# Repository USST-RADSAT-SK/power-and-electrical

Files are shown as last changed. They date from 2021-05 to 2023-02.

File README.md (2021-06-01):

# power-and-electrical

## How to Download GitBash
  
  Gitbash is a terminal that you use to execute "git" commands and its highly recommended that you download it 
  
  Use the following link
  https://git-scm.com/downloads
  
## How to Copy a Repo

  Make a folder on your local drive (I make a folder on my desktop)
  
  go into that folder and right click and open gitbash at that location
  
  find the green button in the github that says "Code"
  
  click and copy the URL
  
  go back into the gitbash enter
  
  "git clone [URL]" 

  Now if you want to make changes to a file please make a branch 
  
## How To View a Branch

  Say you want to do a quick check on the progress for the PCB board
  
  use the following commands in git bash
  
  "git checkout [name of branch]"
  
  In the case that KiCad is not updating automatically use the following procedure:
  
  - open project file with "open with..." in file directory 

  If you quickly want to check when the last changes were done to a branch use
  
  "git log"
  
  scroll up & you will see the most recent commit and who did it
  
## How To Make a Branch
  
  a branch is like a copy of files that you can edit on your local drive where you dont have to worry about messing up the main code
  
  make sure you are in the right directory
  
  "git branch [name of the branch]"

  keep the name of the branch short and sweet no need to make it complitcated

## How to Commit a Change

  Once gitbash is opened you want to make sure you are in the right file directory you want to use the command 
  
  "git status"
  
  to check if you saved your files (it will show up as red)
  
  "Git add [filename]"
  
  this will prepare your file to be commited
  
  "git status"
  
  the file name should be green now
  
  "git commit -m "[changes you made as a comment]" "
  
  this will commit your changes 
  
  "git push"
  
  this will save your changes into the branch

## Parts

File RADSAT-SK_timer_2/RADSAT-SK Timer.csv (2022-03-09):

Source: | C:\Users\gundo\Desktop\P&E\power-and-electrical\RADSAT-SK Timer\RADSAT-SK Timer.sch
Date: | 2022-03-02 14:46
Tool: | Eeschema (5.1.12)-1
Generator: | C:\Program Files\KiCad\bin\scripting\plugins/bom_csv_grouped_by_value_with_fp.py
Component Count: | 124
Ref | Qnty | Value | Cmp name | Footprint | Description | Vendor
BT201, BT202, | 2 | Battery_Cell | Battery_Cell | Battery:BatteryHolder_Keystone_1060_1x2032 | Single-cell battery
C101, C102, C105, C106, C107, C108, | 6 | 330u | CP | Capacitor_Tantalum_SMD:CP_EIA-7343-30_AVX-N_Pad2.25x2.55mm_HandSolder | Polarized capacitor
C103, C104, C109, C110, C111, C112, C113, C114, | 8 | 100n | C | Capacitor_SMD:C_0805_2012Metric | Unpolarized capacitor
C204, | 1 | 10uF | C | Capacitor_SMD:C_0805_2012Metric | Unpolarized capacitor
C205, | 1 | 0.1uF | C | Capacitor_SMD:C_0805_2012Metric | Unpolarized capacitor
C207, | 1 | 1.5nF | C | Capacitor_SMD:C_0805_2012Metric | Unpolarized capacitor
C208, | 1 | 22uF | C | Capacitor_SMD:C_1210_3225Metric_Pad1.33x2.70mm_HandSolder | Unpolarized capacitor
D201, | 1 | 5.0SMDJ5.0A | SM6T6V8A | Diode_SMD:D_SMC_Handsoldering | 600W unidirectional Transil Transient Voltage Suppressor, 6.8Vrwm, DO-214AA
D203, | 1 | MBRM120LT3G | D_Schottky | Diode_SMD:D_Powermite_AK | Schottky diode
D204, | 1 | BAT54CDW | BAT54CDW | Package_TO_SOT_SMD:SOT-363_SC-70-6_Handsoldering | Schottky diode array 2 pair Com K
D205, D206, | 2 | LED | LED | LED_SMD:LED_0603_1608Metric_Pad1.05x0.95mm_HandSolder | Light emitting diode
H101, H102, H103, H104, | 4 | MountingHole | MountingHole | MountingHole:MountingHole_3.2mm_M3_ISO7380_Pad_TopBottom | Mounting Hole without connection
J101, J103, | 2 | Conn_02x26_Odd_Even | Conn_02x26_Odd_Even | Connector_PinSocket_2.54mm:PinSocket_2x26_P2.54mm_Vertical | Generic connector, double row, 02x26, odd/even pin numbering scheme (row 1 odd numbers, row 2 even numbers), script generated (kicad-library-utils/schlib/autogen/connector/)
J201, | 1 | Conn_01x07 | Conn_01x07 | Connector_Molex:Molex_PicoBlade_53047-0710_1x07_P1.25mm_Vertical | Generic connector, single row, 01x07, script generated (kicad-library-utils/schlib/autogen/connector/)
J202, | 1 | Conn_01x05 | Conn_01x05 | Connector_Hirose:Hirose_DF13-05P-1.25DSA_1x05_P1.25mm_Vertical | Generic connector, single row, 01x05, script generated (kicad-library-utils/schlib/autogen/connector/)
J203, | 1 | Conn_01x03 | Conn_01x03 | Connector_Hirose:Hirose_DF13C_CL535-0403-5-51_1x03-1MP_P1.25mm_Vertical | Generic connector, single row, 01x03, script generated (kicad-library-utils/schlib/autogen/connector/)
J204, J205, J206, | 3 | Conn_01x02 | Conn_01x02 | Connector_Hirose:Hirose_DF13-02P-1.25DSA_1x02_P1.25mm_Vertical | Generic connector, single row, 01x02, script generated (kicad-library-utils/schlib/autogen/connector/)
L201, | 1 | 10uH | L | Sumida_inductor:Sumida_inductor | Inductor
Q101, Q102, Q103, Q104, Q105, Q106, Q107, Q108, Q109, Q201, Q202, Q204, Q205, Q206, Q207, | 15 | IRLML2060 | IRLML2060 | Package_TO_SOT_SMD:SOT-23_Handsoldering | 1.2A Id, 60V Vds, 480mOhm Rds, N-Channel HEXFET Power MOSFET, SOT-23
R101, R103, R107, R113, R114, R117, R118, R124, R126, R203, R221, | 11 | 1M | R | Resistor_SMD:R_0805_2012Metric | Resistor
R102, R111, R115, R116, R133, R134, R202, R204, R211, R213, R215, R220, | 12 | 100 | R | Resistor_SMD:R_0805_2012Metric | Resistor
R104, R119, R120, | 3 | 1K | R | Resistor_SMD:R_0805_2012Metric | Resistor
R105, R121, R122, | 3 | 3.48M | R | Resistor_SMD:R_0805_2012Metric | Resistor
R106, R123, R125, | 3 | 442K | R | Resistor_SMD:R_0805_2012Metric | Resistor
R108, R109, R110, R112, R127, R128, R129, R130, R131, R132, R135, R136, R209, R210, R212, R214, R216, R217, | 18 | 1k | R | Resistor_SMD:R_0805_2012Metric | Resistor
R137, | 1 | 5.1M | R | Resistor_SMD:R_0805_2012Metric | Resistor
R201, | 1 | 3M | R | Resistor_SMD:R_0805_2012Metric | Resistor
R205, | 1 | 60.4K | R | Resistor_SMD:R_0805_2012Metric | Resistor
R206, | 1 | 15k | R | Resistor_SMD:R_0805_2012Metric | Resistor
R207, | 1 | 619k | R | Resistor_SMD:R_0805_2012Metric | Resistor
R208, | 1 | 200k | R | Resistor_SMD:R_0805_2012Metric | Resistor
SW201, SW202, SW203, SW204, SW205, SW206, | 6 | SW_Push | SW_Push | Connector_Hirose:Hirose_DF13-02P-1.25DSA_1x02_P1.25mm_Vertical | Push button switch, generic, two pins
U101, U102, U103, | 3 | LM397MF | LM397MF | Package_TO_SOT_SMD:TSOT-23-5_HandSoldering
U104, | 1 | CD4052B | CD4052B | Package_SO:TSSOP-16_4.4x5mm_P0.65mm | CMOS double 4-channel analog multiplexer/demultiplexer, TSSOP-16/DIP-16/SOIC-16
U202, | 1 | LTC3440EMSPBF | LTC3440EMSPBF | Package_SO:MSOP-10_3x3mm_P0.5mm
U230, U240, U250, U260, | 4 | CPC1117N | CPC1117N | Package_SO:SOP-4_3.8x4.1mm_P2.54mm | Form B, Solid State Relay (Photo MOSFET) 60V, 0.15A, 16Ohm, SO-4

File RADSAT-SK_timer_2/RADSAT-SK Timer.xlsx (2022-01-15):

Source: | C:\Users\riley\USST\RADSAT-SK\power-and-electrical\RADSAT-SK Timer\RADSAT-SK Timer.sch
Date: | 10/20/2021 6:26PM
Tool: | Eeschema (5.1.10)-1
Generator: | C:\Program Files\KiCad\bin\scripting\plugins/bom_csv_grouped_by_value_with_fp.py
Component Count: | 116
Total Component Cost: | $80.62
Ref | Qnty | Value | Cmp name | Footprint | Description/Notes | Datasheet | Product URL | Price | Related Components | Price2 | Price total | Column1
BT201, BT202, | 2 | Battery_Cell | Battery_Cell | Battery:BatteryHolder_Keystone_1060_1x2032 | BATT HLDR COIN 20MM 1/2 CEL SMD | https://www.keyelco.com/userAssets/file/M65p3.pdf | https://www.digikey.ca/en/products/detail/keystone-electronics/1060TR/303557 | $2.12 | https://www.mouser.ca/ProductDetail/Panasonic-Industrial-Devices/CR-2025-F2N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 | $1.61 | $7.46
C101, C102, C105, C106, C107, C108, | 6 | 330u | CP | Capacitor_Tantalum_SMD:CP_EIA-7343-30_AVX-N_Pad2.25x2.55mm_HandSolder | 330 µF Molded Tantalum Capacitors 10 V 2917 (7343 Metric) 500mOhm @ 100kHz |  | https://www.digikey.ca/en/products/detail/kyocera-avx/F931A337KNC/4005190 | $3.36 |  |  | $20.16
C103, C104, C109, C110, C111, C112, C113, C114, C204 | 9 | 100n | C | Capacitor_SMD:C_0805_2012Metric | Unpolarized capacitor |  | https://www.digikey.ca/en/products/detail/tdk-corporation/C2012X7R1H104K085AA/2732969 | $0.15 |  |  | $1.35
C204, | 1 | 10uF | C | Capacitor_SMD:C_0805_2012Metric | 10 µF ±20% 6.3V Ceramic Capacitor X5R 0805 (2012 Metric) | https://www.yuden.co.jp/productdata/catalog/mlcc06_e.pdf | https://www.digikey.ca/en/products/detail/taiyo-yuden/JMK212BJ106MG-T/1169928 | $0.41 |  |  | $0.41
C207, | 1 | 1.5nF | C | Capacitor_SMD:C_0805_2012Metric | Unpolarized capacitor |  | https://www.digikey.ca/en/products/detail/tdk-corporation/C2012X5R1E155K125AA/2733062 | $0.41 |  |  | $0.41
C208, | 1 | 22uF | C | Capacitor_SMD:C_1210_3225Metric | 22 µF ±20% 6.3V Ceramic Capacitor X5R 1210 (3225 Metric) | https://ds.yuden.co.jp/TYCOMPAS/ut/detail?pn=JMK325BJ226MY-T%20%20&u=M | https://www.digikey.ca/en/products/detail/taiyo-yuden/JMK325BJ226MY-T/930737 | $1.09 |  |  | $1.09
D205 | 1 | LED | LED | LED_SMD:LED_0603_1608Metric_Pad1.05x0.95mm_HandSolder | Green 571nm LED Indication - Discrete 2V 0603 (1608 Metric) | https://optoelectronics.liteon.com/upload/download/DS22-2000-074/LTST-C190KGKT.PDF | https://www.digikey.ca/en/products/detail/lite-on-inc/LTST-C190KGKT/386815 | $0.33 |  |  | $0.33
D206 | 1 | LED | LED | LED_SMD:LED_0603_1608Metric_Pad1.05x0.95mm_HandSolder | Orange 605nm LED Indication - Discrete 2V 0603 (1608 Metric) |  | https://www.digikey.ca/en/products/detail/lite-on-inc/LTST-C191KFKT/386833 | $0.33 |  |  | $0.33
D201, | 1 | 5.0SMDJ5.0A | D_Zener | Diode_SMD:D_SMC_Handsoldering | 9.2V Clamp 543.6A Ipp Tvs Diode Surface Mount DO-214AB (SMC) | https://www.bourns.com/docs/product-datasheets/5-0smdj.pdf | https://www.digikey.ca/en/products/detail/bourns-inc/5-0SMDJ5-0A/9341763 | $2.33 | https://www.digikey.ca/en/products/detail/vishay-general-semiconductor-diodes-division/BZX884B5V6L-G3-08/14312759 |  | $2.33
D203, | 1 | MBRM120LT3G | D_Schottky | Diode_SMD:D_Powermite_AK | DIODE SCHOTTKY 20V 1A POWERMITE | from boost circuit | https://www.onsemi.com/pdf/datasheet/mbrm120l-d.pdf | https://www.digikey.ca/en/products/detail/onsemi/MBRM120LT3G/1748989 | $0.76 |  |  | $0.76
D204 | 1 | BAT54CDW | BAT54CDW | Package_TO_SOT_SMD:SOT-363_SC-70-6_Handsoldering | Diode Array 2 Pair Common Cathode Schottky 30 V 200mA (DC) Surface Mount 6-TSSOP, SC-88, SOT-363 | https://www.panjit.com.tw/upload/datasheet/BAT54TW_SERIES.pdf | https://www.digikey.ca/en/products/detail/panjit-international-inc/BAT54CDW-R1-00001/14660464 | $0.55 |  |  | $0.55
J101, J103, | 2 | Conn_02x26_Odd_Even | Conn_02x26_Odd_Even | Connector_PinSocket_2.54mm:PinSocket_2x26_P2.54mm_Vertical | CSKB |  | https://www.digikey.ca/en/products/detail/samtec-inc/ESQ-126-39-G-D/3601055 |  |  |  | $0.00 |  | crimps?
J201, | 1 | Conn_01x07 | Conn_01x07 | Connector_Molex:Molex_PicoBlade_53047-0710_1x07_P1.25mm_Vertical | Molex Picoblade 53047 Header and accompanying Picoblade 51047 Connector |  | https://www.digikey.ca/en/products/detail/molex/0530470710/242858 | $0.61 | https://www.digikey.ca/en/products/detail/molex/0510470700/4693261 | $0.52 | $1.13 |  | https://www.digikey.ca/en/products/detail/molex/0500588000/634442
J202, | 1 | Conn_01x05 | Conn_01x05 | Connector_Hirose:Hirose_DF13-05P-1.25DSA_1x05_P1.25mm_Vertical | Generic connector, single row, 01x05, | https://www.mouser.ca/datasheet/2/185/DF13_Catalog_D31687_en-2486995.pdf | https://www.mouser.ca/ProductDetail/Hirose-Connector/DF13-5P-125DSA?qs=Ux3WWAnHpjDJWf8XCjmDFw%3D%3D | $0.59 |  |  | $0.59
J203, | 1 | Conn_01x03 | Conn_01x03 | Connector_Hirose:Hirose_DF13-03P-1.25DSA_1x03_P1.25mm_Vertical | Generic connector, single row, 01x03, |  | https://www.digikey.ca/en/products/detail/hirose-electric-co-ltd/DF13-3P-1-25V-75/9170629 | $0.59 |  |  | $0.59 |  | no vertical through hole :(
J210, (REMOVED WITH RBF CHARGING PIN) | 0 | ZX62WRD-B-5PC | ZX62WRD-B-5PC | CONN_ZX62WRD-B-5PC_HIR:CONN_ZX62WRD-B-5PC_HIR | USB Connector |  | https://www.digikey.ca/en/products/detail/hirose-electric-co-ltd/ZX62WRD-B-5PC/3761053 | $1.76 |  |  | $0.00
L201, | 1 | 10uH | L | **NONSTANDARD NEED TO CREATE*** | FIXED IND 10UH 1A 128.3 MOHM SMD | from boost circuit | https://products.sumida.com/products/pdf/CDRH4D28.pdf | https://www.digikey.ca/en/products/detail/sumida-america-components-inc/CDRH4D28NP-100NC/1059478 | $1.48 |  |  | $1.48
Q101, Q102, Q103, Q104, Q105, Q106, Q107, Q108, Q109, Q201, Q202, Q204, Q205, Q206 ,Q207 | 15 | IRLML2060 | IRLML2060 | Package_TO_SOT_SMD:SOT-23_Handsoldering | 1.2A Id, 60V Vds, 480mOhm Rds, N-Channel HEXFET Power MOSFET, SOT-23 | https://www.infineon.com/dgdl/irlml2060pbf.pdf?fileId=5546d462533600a401535664b7fb25ee | https://www.digikey.ca/en/products/detail/infineon-technologies/irlml2060trpbf/2271899 | $0.63 |  |  | $9.45
R101, R103, R107, R113, R114, R117, R118, R124, R126, R203, R221 | 11 | 1M | R | Resistor_SMD:R_0805_2012Metric | Resistor |  | https://www.digikey.ca/en/products/detail/stackpole-electronics-inc/RMCF0805JT1M00/1757878 | $0.03 |  |  | $0.32
R102, R111, R115, R116, R133, R134, R202, R204, R211, R213, R215, R220 | 12 | 100 | R | Resistor_SMD:R_0805_2012Metric | Resistor |  | https://www.digikey.ca/en/products/detail/stackpole-electronics-inc/RNCP0805FTD100R/2240209 | $0.11 |  |  | $1.28
R104, R108, R109, R110, R112, R119, R120, R127, R128, R129, R130, R131, R132, R135, R136, R209, R210, R212, R214, R216, R217 | 21 | 1k | R | Resistor_SMD:R_0805_2012Metric | Resistor |  | https://www.digikey.ca/en/products/detail/stackpole-electronics-inc/RMCF0805JT1K00/1757881 | $0.03 |  |  | $0.61
R105, R121, R122, | 3 | 3.48M | R | Resistor_SMD:R_0805_2012Metric | Resistor |  | https://www.digikey.ca/en/products/detail/vishay-dale/CRCW08053M48FKEA/1176076 | $0.15 |  |  | $0.45
R106, R123, R125, | 3 | 442K | R | Resistor_SMD:R_0805_2012Metric | Resistor |  | https://www.digikey.ca/en/products/detail/stackpole-electronics-inc/RMCF0805FT442K/1713153 | $0.15 |  |  | $0.45
R137, | 1 | 5.1M | R | Resistor_SMD:R_0805_2012Metric | Resistor |  | https://www.digikey.ca/en/products/detail/stackpole-electronics-inc/RMCF0805FT5M10/1713191 | $0.15 |  |  | $0.15
R201, | 1 | 3M | R | Resistor_SMD:R_0805_2012Metric | Resistor |  | https://www.digikey.ca/en/products/detail/stackpole-electronics-inc/RMCF0402JT3M00/1712450 |  |  |  | $0.00
R205, | 1 | 60.4K | R | Resistor_SMD:R_0805_2012Metric | Resistor |  | https://www.digikey.ca/en/products/detail/stackpole-electronics-inc/RMCF0805FT60K4/1760362 | $0.15 |  |  | $0.15
R206, | 1 | 15k | R | Resistor_SMD:R_0805_2012Metric | Resistor |  | https://www.digikey.ca/en/products/detail/stackpole-electronics-inc/RMCF0805FT15K0/1760487 | $0.15 |  |  | $0.15
R207, | 1 | 619k | R | Resistor_SMD:R_0805_2012Metric | Resistor |  | https://www.digikey.ca/en/products/detail/stackpole-electronics-inc/RMCF0805FT619K/1713291 | $0.15 |  |  | $0.15
R208, | 1 | 200k | R | Resistor_SMD:R_0805_2012Metric | Resistor |  | https://www.digikey.ca/en/products/detail/stackpole-electronics-inc/RMCF0805JT200K/1757911 | $0.15 |  |  | $0.15
J204, J205, J206, SW201, SW202, SW203, SW204, SW205, SW206, | 9 | SW_Push | Conn_01x02 | Connector_Hirose:Hirose_DF13-02P-1.25DSA_1x02_P1.25mm_Vertical | Connecotrs for wires to 331XS4-T honeywell switch | https://www.hirose.com/product/document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 | https://www.digikey.ca/en/products/detail/hirose-electric-co-ltd/DF13-2P-1-25DSA-76/9170620 | $0.58 |  |  | $5.19
U101, U102, U103, | 3 | LM397MF | LM397MF | Package_TO_SOT_SMD:TSOT-23-5_HandSoldering |  | https://www.ti.com/general/docs/suppproductinfo.tsp?distId=10 | https://www.digikey.ca/en/products/detail/texas-instruments/LM397MF/3701445 | $1.96 |  |  | $5.88
U104, | 1 | CD4052B | CD4052B | Package_SO:TSSOP-16_4.4x5mm_P0.65mm | CMOS double 4-channel analog multiplexer/demultiplexer, TSSOP-16/DIP-16/SOIC-16 | http://www.ti.com/lit/ds/symlink/cd4052b.pdf | https://www.digikey.ca/en/products/detail/texas-instruments/CD4052BPWRG3/2596791 | $0.81 |  |  | $0.81
U202, | 1 | LTC3440EMSPBF | LTC3440EMSPBF | Package_SO:MSOP-10_3x3mm_P0.5mm | Buck-Boost Switching Regulator IC Positive Adjustable 2.5V 1 Output 600mA | https://www.analog.com/media/en/technical-documentation/data-sheets/3440fd.pdf | https://www.digikey.ca/en/products/detail/analog-devices-inc/LTC3440EMS-PBF/890929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 | $9.61 |  |  | $9.61
U230,U240,U250,U260 | 4 | CPC1117N | SSR_SPST-NC | Package_SO:SOP-4_3.8x4.1mm_P2.54mm | Solid State SPST-NC (1 Form B) 4-SOP (0.150", 3.81mm) | https://www.ixysic.com/home/pdfs.nsf/www/CPC1106N.pdf/$file/CPC1106N.pdf | https://www.digikey.ca/en/products/detail/ixys-integrated-circuits-division/CPC1106NTR/3077493 | $1.71 |  |  | $6.84
E | e | e | e | e | e | e | e | e | e | e | e | e

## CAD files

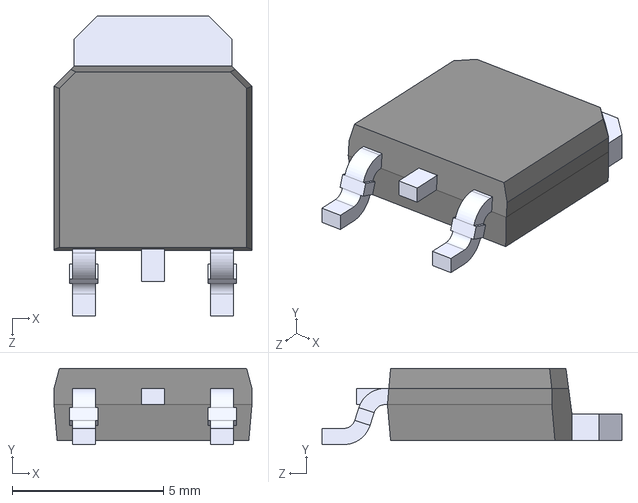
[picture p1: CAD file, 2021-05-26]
RADSAT-SK_timer_2/IRLRML2803/DPAK229P990X239-3N.step
6.54 x 2.51 x 9.91 mm

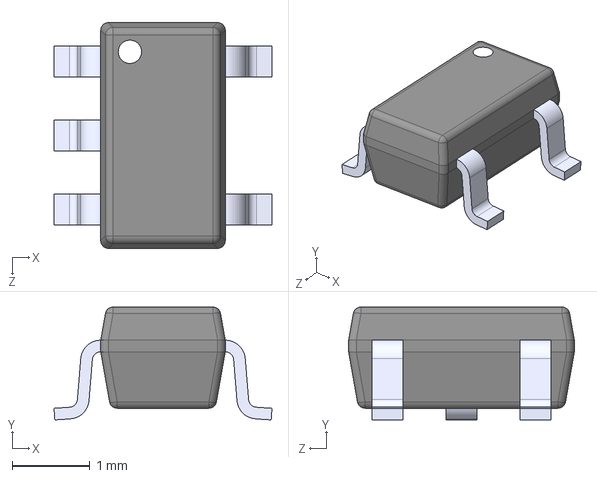
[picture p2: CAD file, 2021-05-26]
RADSAT-SK_timer_2/LM397/LM397MF.STEP
2.80 x 1.45 x 2.90 mm

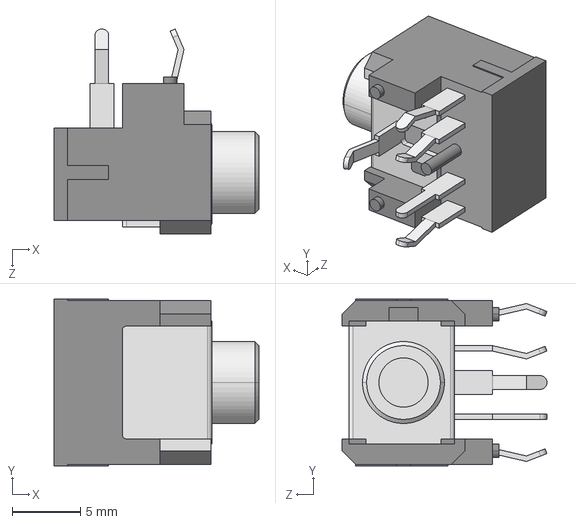
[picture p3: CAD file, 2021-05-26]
RADSAT-SK_timer_2/RBF/CUI_DEVICES_SJ1-3545N.step
15.0 x 12.2 x 15.0 mm

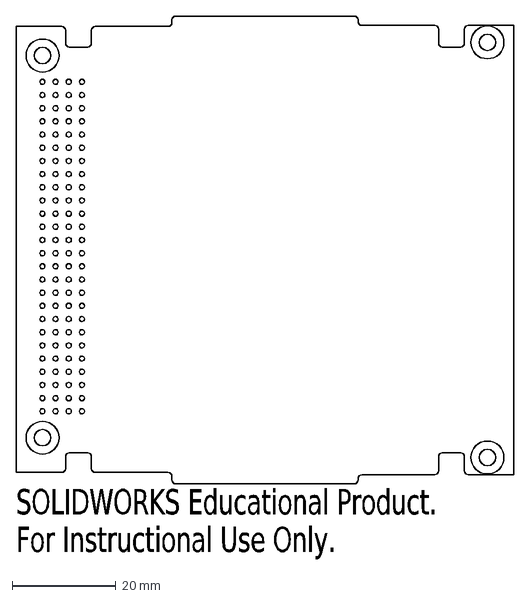
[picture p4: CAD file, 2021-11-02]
RADSAT-SK_timer_2/Timer_Board.DXF
SOLIDWORKS Educational Product.
For Instructional Use Only.

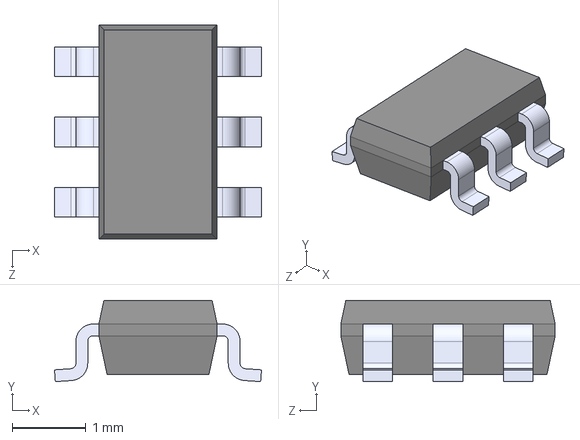
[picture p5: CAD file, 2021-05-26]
RADSAT-SK_timer_2/TPS3700/TPS3700DDCR.step
2.80 x 1.10 x 2.90 mm

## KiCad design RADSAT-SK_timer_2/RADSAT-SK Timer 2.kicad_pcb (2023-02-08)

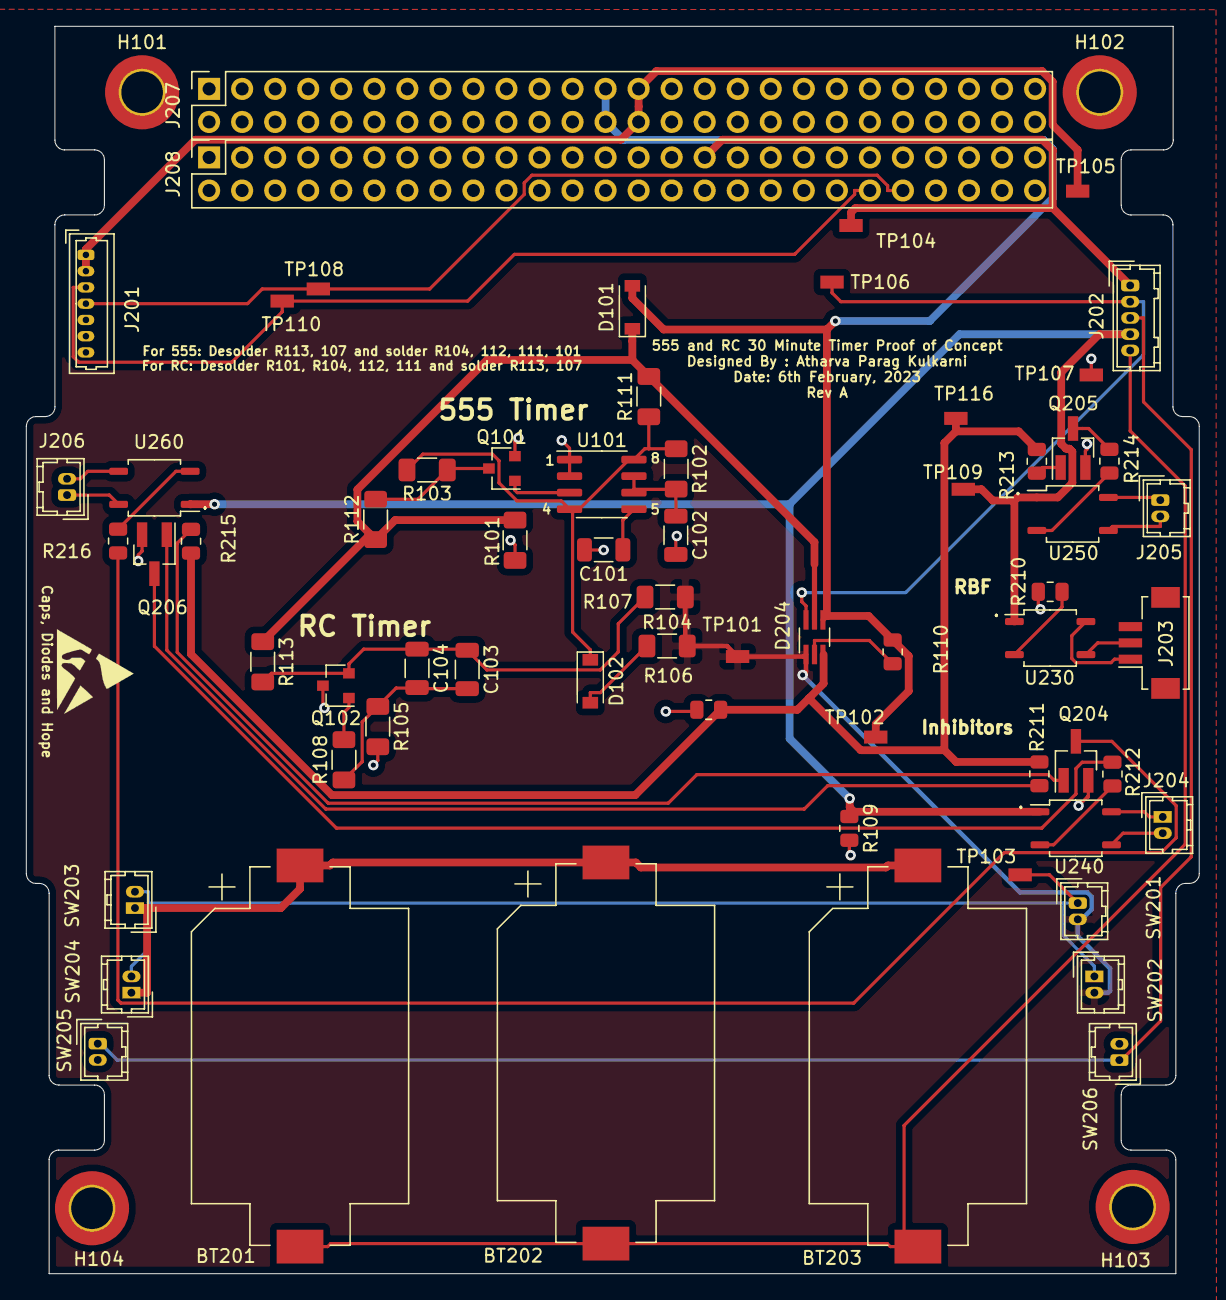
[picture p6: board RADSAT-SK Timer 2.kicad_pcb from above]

Board: 2 copper layers, 90.2 x 95.9 mm, 69 parts (0 on the bottom side), 43 nets.

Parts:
BT201, BT202, BT203: Battery_Cell; BatteryHolder_Keystone_1060_1x2032
C101: 10nF; C_1206_3216Metric
C102, C103, C104: 600uF; C_1206_3216Metric
D101, D102: SBR80520LT1G; D_SOD-123
D204: BAT54CDW; SOT-363_SC-70-6_Handsoldering
H101, H102, H103, H104: MountingHole; MountingHole_3.2mm_M3_ISO7380_Pad_TopBottom
J201: Conn_01x07; Molex_PicoBlade_53047-0710_1x07_P1.25mm_Vertical
J202: Conn_01x05_Female; Hirose_DF13-05P-1.25DSA_1x05_P1.25mm_Vertical
J203: Conn_01x03; Hirose_DF13C_CL535-0403-5-51_1x03-1MP_P1.25mm_Vertical
J204, J205, J206: Conn_01x02; Hirose_DF13-02P-1.25DSA_1x02_P1.25mm_Vertical
J207, J208: Conn_02x26_Odd_Even; PinSocket_2x26_P2.54mm_Vertical
Q101: 2N7002E; SOT-23
Q102: DSS4240T-7; SOT-23
Q204, Q205, Q206: IRLML2060; SOT-23_Handsoldering
R101: 10k; R_1206_3216Metric_Pad1.30x1.75mm_HandSolder
R102, R108: 3M; R_1206_3216Metric_Pad1.30x1.75mm_HandSolder
R103: 1M; R_1206_3216Metric_Pad1.30x1.75mm_HandSolder
R104, R105, R107, R111, R112, R113: 0; R_1206_3216Metric_Pad1.30x1.75mm_HandSolder
R106, R109: 1M; R_0805_2012Metric
R110: 40; R_0805_2012Metric
R210: 320; R_0805_2012Metric
R211, R213, R215: 25; R_0805_2012Metric
R212, R214, R216: 260; R_0805_2012Metric
SW201, SW202, SW203, SW204, SW205, SW206: SW_Push; Hirose_DF13-02P-1.25DSA_1x02_P1.25mm_Vertical
TP101, TP102, TP103, TP104, TP105, TP106, TP107, TP108, TP109, TP110, TP116: TestPoint; HARWIN_S2761-46R
U101: TLC555CDR; SOIC-8_3.9x4.9mm_P1.27mm
U230, U240, U250, U260: CPC1114N; SOP-4_3.8x4.1mm_P2.54mm

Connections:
+3V3: J201.1, J201.2, J207.27, J207.28, TP105.1
+5V: D101.2, D204.4, J207.25, J207.26, R110.2, TP102.1
+BATT: D204.1, R104.2, R107.2, SW201.2, SW202.2, TP101.1
/Inhib_in: D204.3, R106.1, R211.1, R213.1, R215.1, TP116.1
A: BT201.1, BT202.1, BT203.1, SW203.1, SW204.1
GND: C101.2, C102.2, J201.5, J201.6, J201.7, J207.29, J207.30, J207.32, Q101.2, Q102.3, Q204.2, Q205.2, Q206.2, R101.2, R105.2, R106.2, R109.2, R210.2, SW205.2, SW206.2, TP107.1, U101.1, U101.2
I2C_CLK: J201.4, J208.44, TP108.1
I2C_DATA: J201.3, J208.42, TP110.1
InhibV+: J202.4, R109.1, TP109.1, U230.1, U240.1, U250.1, U260.1
Inhib_EN: D101.1, D204.5, R101.1, R111.2, R112.1, R113.1
unnamed: BT201.2, BT202.2, BT203.2, J202.5
unnamed: C101.1, U101.5
unnamed: C102.1, R102.2, U101.6, U101.7
unnamed: C103.1, C104.1, Q102.2, R107.1, R113.2
unnamed: C103.2, C104.2, R105.1, R108.1
unnamed: D102.1, R102.1, R103.2, R111.1, U101.4, U101.8
unnamed: D102.2, R104.1
unnamed: D204.2, R110.1
unnamed: D204.6, J202.2, TP106.1
unnamed: J202.3, SW205.1, SW206.1
unnamed: J203.1, U230.4
unnamed: J203.2, U230.3
unnamed: J204.1, U240.4
unnamed: J204.2, U240.3
unnamed: J205.1, U250.4
unnamed: J205.2, U250.3
unnamed: J206.1, U260.4
unnamed: J206.2, U260.3
unnamed: Q101.1, U101.3
unnamed: Q101.3, R103.1, R112.2
unnamed: Q102.1, R108.2
unnamed: Q204.1, R215.2
unnamed: Q204.3, R216.2
unnamed: Q205.1, R213.2
unnamed: Q205.3, R214.2
unnamed: Q206.1, R211.2
unnamed: Q206.3, R212.2
unnamed: R210.1, U230.2
unnamed: R212.1, U240.2
unnamed: R214.1, U250.2
unnamed: R216.1, U260.2
unnamed: SW201.1, SW202.1, SW203.2, SW204.2, TP103.1
USB_Charge: J202.1, J208.31, TP104.1

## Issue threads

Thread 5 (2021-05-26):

Add ports for switches

ChrisAmaya, 2021-05-26:
DF13-2P-125H

rileyrox-arn725, 2021-06-01:
DF13-2P-125H: This is a surface mount right angle header and not molex microfit as outlined by the design document for the timerboard currently on the dropbox

These are 2 and 4 pin throughole microfit3.0 Molex connectors that already have a footprint in the kicad libraries
Both are available on digikey sold individually for 0.87 and 1.49 CAD respectively
0436500215: 2 pin
0436500415: 4 pin

<!--EndFragment-->

ChrisAmaya, 2021-06-02:
For the connectors by the battery, it might be a good idea to use vertical (inhibits, RBF) because the battery board is above the timerboard

rest of connectors are whatever makes sense

MicroUSB should not be vertical

ChrisAmaya, 2021-06-02:
15.2 mm of clearance between timerboard and battery

ChrisAmaya, 2021-06-02:
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

ChrisAmaya, 2021-06-02:
![Uploading image.png…]()

ChrisAmaya, 2021-06-02:
![Uploading image.png…]()

rileyrox-arn725, 2021-06-11:
Through-hole header vertical mount 2,3,4 pins
DF13-2P-1.25DSA
DF13-3P-1.25DSA
DF13-4P-1.25DSA

rileyrox-arn725, 2021-06-11:
corresponding connectors
DF13-2S-1.25C
DF13-3S-1.25C
DF13-4S-1.25C

Closed 2022-03-11.

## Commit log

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2021-06-02 Pc bresize (#7)
    * PCB has been resized and the layer redone to fit the new shape, assumed a cent red stack for the main connector. No rounded edges.
    * figured out how to do rounded corners also pull request test
    * Rounded corners X24
    [1060TR.step, RADSAT-SK Timer 2.sch, RADSAT-SK Timer.kicad_pcb]
2021-06-15 deleted files for a battery holder that we are not using, -had added it myself- rearanged some of the layout to get outer edge for ports, changed to df13 hirose ports, added dummy usb connector.
    [1060TR.step, RADSAT-SK Timer 2.sch, RADSAT-SK Timer.kicad_pcb]
2021-09-16 Retrace (#8)
    * Schematic: Added- 2 more inhibit ports Added- RBF Ports In and Out Connected USb Charger to connector H1-32. Layout: Port positioning and adjustments to some existing circuitry for better tracing.
    * schematic saved with above changes
    * Retraced the board
    * added starting place for RBF timer
    * Mason has updated some footprints
    * Change to the 7 pin Antenna on the PCB
    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
    [RADSAT-SK Timer 2.sch, RADSAT-SK Timer.kicad_pcb, RADSAT-SK Timer.sch]
2021-09-16 Revert "Retrace (#8)" (#9)
    This reverts commit b83679d15abd0ed1c357c8fd6e32726f91c1f504.
    [RADSAT-SK Timer 2.sch, RADSAT-SK Timer.kicad_pcb, RADSAT-SK Timer.sch]
2021-09-16 Retrace (#10)
    * added RBF stuff to PCB
    * moved some traces
    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
    [RADSAT-SK Timer 2.sch, RADSAT-SK Timer.kicad_pcb, RADSAT-SK Timer.sch]
2021-09-25 Revert "Retrace (#8)" (#11)
    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
    [RADSAT-SK Timer 2.sch, RADSAT-SK Timer.kicad_pcb, RADSAT-SK Timer.sch]
2021-09-25 Deleted a bunch of backups and unnecessary project files
    [RADSAT-SK Timer 2.sch, RADSAT-SK Timer.sch]
2021-09-25 Added in the RBF connector and setup to coincells, need to add inhibitor logic and find components
    [RADSAT-SK Timer 2.sch]
2021-09-26 1.Added USB Header, Footprint and lib files 2. got rid of the rescue library by reassigning the symbols to proper libraries in the project 3. assigned footprints to all components, though BOM still M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
    [0436500200--3DModel-STEP-231308.STEP, 0436500400--3DModel-STEP-231308.STEP, RADSAT-SK Timer 2.sch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]
2021-09-26 PCBheader layout version 1, Note Main Bus Headers are on back of PCB to line pin 1 with batt board, RBF output is 3pin??? Need proper allignment of Main header
    [RADSAT-SK Timer 2.sch]
2021-09-27 Added missing Capacitor value from old schematic in the slack discussion
    [RADSAT-SK Timer 2.sch]
2021-10-01 Cleaned Up the USb footprint and updated the libraries to play nice with KiCad
    [RADSAT-SK Timer 2.sch, RADSAT-SK Timer.kicad_pcb]
2021-10-01 More Library management, added text to pcb to identify easily connectors, Added a cool custom USST RADSAT-SK Logo to the project, may need to be scaled down or placed on back of board
    [RADSAT-SK Timer 2.sch, RADSAT-SK Timer.kicad_pcb]
2021-10-16 added pchannel JFET and Diode logic for inhibitors, edited the layout a bit still not final
    [RADSAT-SK Timer 2.sch, RADSAT-SK Timer.kicad_pcb, RADSAT-SK Timer.sch]
2021-10-21 formatted a BOM and added datasheet urls from previous BOM on the dropbox. Quite dissapointed that like only 2 components were actually sourced and there are no digikey/mouser links associated with a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
    [RADSAT-SK Timer.xlsx]
2021-10-21 Added some more components to the BOM, Still need to figure out HIROSE Connectors, would like to use 2 pin instead of 3 pin. Took forever to figure out the antenna connector that was used
    [RADSAT-SK Timer.xlsx]
2021-10-22 More components to the BOM and fixed footprints on the schematic to mathc chosen parts
    [RADSAT-SK Timer 2.sch, RADSAT-SK Timer.kicad_pcb, RADSAT-SK Timer.xlsx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]
2021-10-22 This commit contains more ccomponent sourcing, mainly a diode array for the inhibitor logic diodes, handsoldering footprints have been chosen for some of the sourced components, see BOM, this should 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
    [RADSAT-SK Timer 2.sch, RADSAT-SK Timer.kicad_pcb, RADSAT-SK Timer.sch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]
2021-10-24 use of a C117 solid state relay and another mosfet for isolated connection of the pins ie we dont care about the pin characteristic now baby
    [RADSAT-SK Timer 2.sch, RADSAT-SK Timer.kicad_pcb]
2021-10-25 actually did the other relays for the inhibits, played around with layout stuff
    [RADSAT-SK Timer 2.sch, RADSAT-SK Timer.kicad_pcb, RADSAT-SK Timer.xlsx]
2021-10-25 Adjusted the BOM to refelct previosu changes, made the 3d Model of the layout look good, swapped the antenna and the usb charger to other sides of the boards
    [RADSAT-SK Timer 2.sch, RADSAT-SK Timer.kicad_pcb, RADSAT-SK Timer.xlsx]
2021-10-26 Noticed that the source on all of the schematic 2 transistors were wrong and needed to be flipped, except on the rbf where it is intentional q Q ~
    [RADSAT-SK Timer 2.sch, RADSAT-SK Timer.kicad_pcb, RADSAT-SK Timer.sch]
2021-10-27 Sourced coin cell battery and tantalum caps, still need to footprint coin cell holders
    [RADSAT-SK Timer 2.sch, RADSAT-SK Timer.kicad_pcb, RADSAT-SK Timer.sch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]
2021-10-28 the RBF relay transistor was redundant, added in another LED and updated diode configuration, resistor sourcing TBD
    [RADSAT-SK Timer 2.sch, RADSAT-SK Timer.kicad_pcb, RADSAT-SK Timer.sch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]
2021-10-28 need to go bakc to previos zener diode for overvoltage
    [RADSAT-SK Timer 2.sch, RADSAT-SK Timer.kicad_pcb, RADSAT-SK Timer.xlsx]
2021-10-28 This contains a completed BOM, Still need to create the Inductor footprint and add sponsor names/logo, then can get into retracing this sucker
    [RADSAT-SK Timer.kicad_pcb, RADSAT-SK Timer.xlsx]
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2021-10-30 Made changes to accomadate the RBF alternate charge plug
    [RADSAT-SK Timer 2.sch, RADSAT-SK Timer.kicad_pcb, RADSAT-SK Timer.sch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]
2021-11-02 single wire was missing, final commit before merging to main
    [RADSAT-SK Timer.kicad_pcb]
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2021-11-08 Modified Inductor Footprint, fixed 3d Model orientation, generated gerbers and drill files. Still unsure about ESD Protection, but can simply remove components from board later.
    [RADSAT-SK Timer 2.sch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]
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2022-03-03 Added Folder for LTSpice Simulations Added a new csv file for TIMB BOM generated by KiCad
    [RADSAT-SK Timer.csv]
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2022-04-15 Chaned solder pad dimentions of replacement 15k resistor, R206
    [RADSAT-SK Timer.kicad_pcb]
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2022-06-20 fixed RBF logic (back to initial state) and added test points
    [RADSAT-SK Timer 2.sch]
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2022-06-26 added galaxia timer in schematic, made footprint for galaxia timer and added to PCB new
    [RADSAT-SK Timer 2.kicad_pcb, RADSAT-SK Timer 2.sch]
2022-06-27 fixed traces
    [RADSAT-SK Timer 2.kicad_pcb]
2022-06-29 swapped antenna connector and RBF port, pushed switches closer to the coin cells and moved silk screen out of vias
    [RADSAT-SK Timer 2.kicad_pcb]
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2022-07-03 fixed CSKB footprint placement
    [RADSAT-SK Timer 2.kicad_pcb]
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2022-07-03 fixed relay connection and routed through hole resistor for current divider
    [RADSAT-SK Timer 2.kicad_pcb, RADSAT-SK Timer 2.sch]
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2022-07-03 corrected I2C CSKB trace
    [RADSAT-SK Timer 2.kicad_pcb]
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2023-02-06 trying to fix "?" in schematic error
    [RADSAT-SK Timer 2-B_Cu.gbr, RADSAT-SK Timer 2-B_Mask.gbr, RADSAT-SK Timer 2-B_Paste.gbr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]
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
